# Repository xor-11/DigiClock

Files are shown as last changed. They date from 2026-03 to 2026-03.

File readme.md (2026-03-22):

<p align="center">
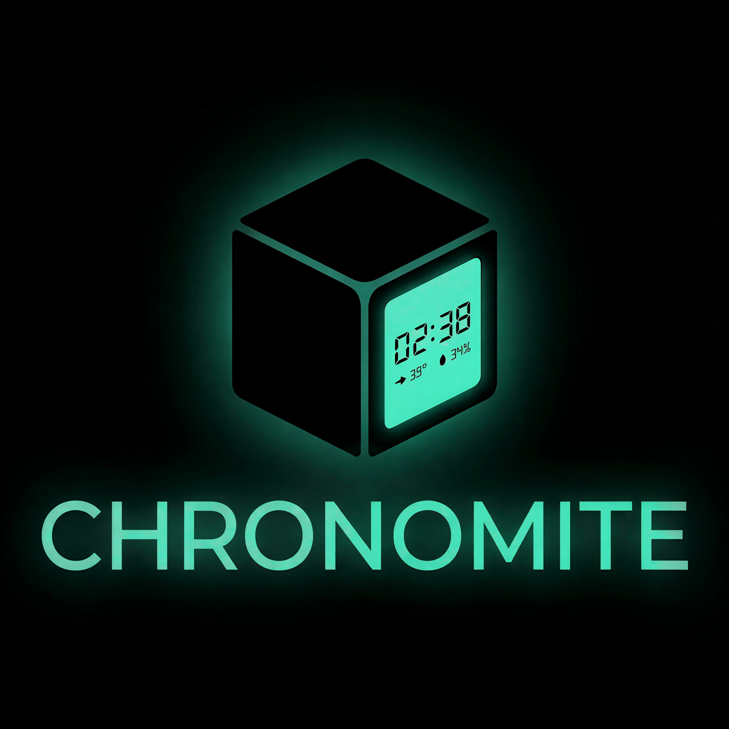
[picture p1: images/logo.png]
DigiClock Logo
  
</p>

<h1 align="center">DigiClock — ATtiny85 OLED Desk Clock</h1>

<p align="center">
  
  
  
  
  
  
</p>

<p align="center">
  A minimal, battery-powered real-time clock with temperature & humidity display,<br>
  built entirely on a Digispark ATtiny85 board with only 8KB of flash memory.<br>
  Housed in a custom 3D-printed enclosure.
</p>

---

## 📸 The Build

<p align="center">
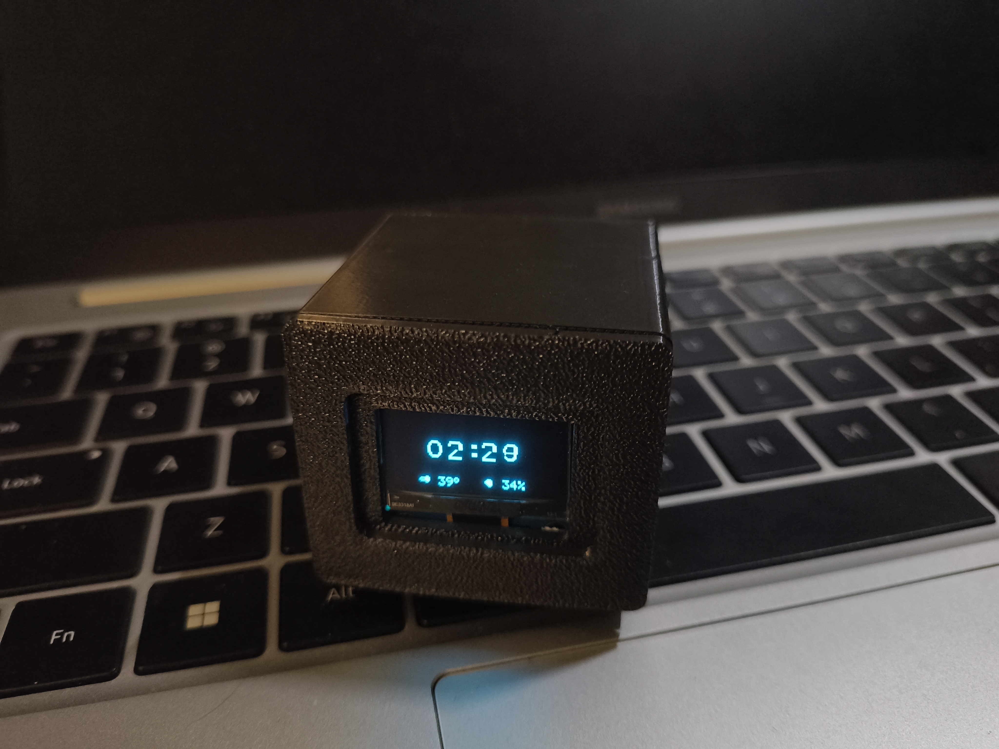
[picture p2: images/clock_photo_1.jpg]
Clock View 1
  
  &nbsp;&nbsp;
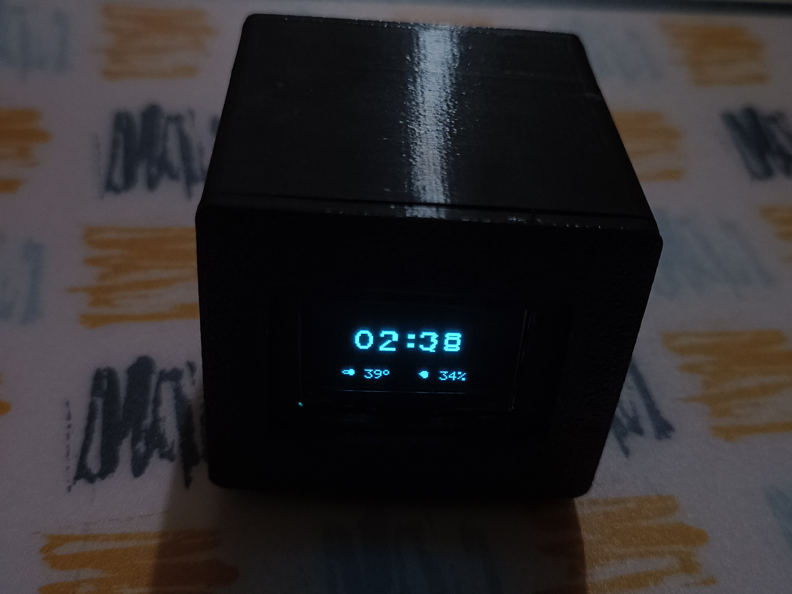
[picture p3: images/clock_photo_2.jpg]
Clock View 2
  
</p>

---

## ✨ Features

- **Real-Time Clock** — Hours, minutes & seconds via DS3231 RTC (I²C)
- **Blinking Colon** — Synced to even/odd seconds for accurate 1Hz blink
- **Temperature Display** — DHT11 reading with 70% scaling calibration
- **Humidity Display** — Relative humidity percentage
- **Smart Refresh** — Only redraws changed digits to eliminate flicker
- **Custom Pixel Fonts** — Hand-crafted 12×16 large digits, 5×8 small font, stored in PROGMEM
- **One-Button Time Set** — Single button adds 10 minutes per press with hold-repeat
- **Battery Powered** — 400mAh Li-Ion cell with TP4056 USB-C charging
- **3D-Printed Enclosure** — Print-ready STL files included
- **Tiny Footprint** — Entire firmware fits in ~6KB flash

---

## 🔌 Pin Diagram

<p align="center">
  Pin Diagram - Wiring Overview
</p>

---

## 🧩 Parts List

<table>
  <tr>
    <th align="center">#</th>
    <th align="left">Component</th>
    <th align="left">Specification</th>
    <th align="center">Qty</th>
  </tr>
  <tr>
    <td align="center">1</td>
    <td>Digispark Board</td>
    <td>ATtiny85 — Micro USB</td>
    <td align="center">1</td>
  </tr>
  <tr>
    <td align="center">2</td>
    <td>OLED Display</td>
    <td>SSD1306 128×64 I²C — 0.96"</td>
    <td align="center">1</td>
  </tr>
  <tr>
    <td align="center">3</td>
    <td>RTC Module</td>
    <td>DS3231 I²C — CR2032 backup</td>
    <td align="center">1</td>
  </tr>
  <tr>
    <td align="center">4</td>
    <td>Temp & Humidity Sensor</td>
    <td>DHT11</td>
    <td align="center">1</td>
  </tr>
  <tr>
    <td align="center">5</td>
    <td>Li-Ion Battery</td>
    <td>3.7V 400mAh</td>
    <td align="center">1</td>
  </tr>
  <tr>
    <td align="center">6</td>
    <td>Charging Module</td>
    <td>TP4056 — USB-C / Micro USB</td>
    <td align="center">1</td>
  </tr>
  <tr>
    <td align="center">7</td>
    <td>Tactile Push Button</td>
    <td>6×6mm momentary</td>
    <td align="center">1</td>
  </tr>
  <tr>
    <td align="center">8</td>
    <td>Connecting Wires</td>
    <td>Dupont / 28AWG silicone</td>
    <td align="center">—</td>
  </tr>
  <tr>
    <td align="center">9</td>
    <td>Enclosure</td>
    <td>3D Printed — STL files included</td>
    <td align="center">1</td>
  </tr>
</table>

---

## 🔗 Connections Summary

<table>
  <tr>
    <th align="center">ATtiny85 Pin</th>
    <th align="left">Connects To</th>
    <th align="center">Protocol</th>
  </tr>
  <tr>
    <td align="center">P0 (SDA)</td>
    <td>OLED SDA &nbsp;•&nbsp; DS3231 SDA</td>
    <td align="center">I²C</td>
  </tr>
  <tr>
    <td align="center">P2 (SCL)</td>
    <td>OLED SCL &nbsp;•&nbsp; DS3231 SCL</td>
    <td align="center">I²C</td>
  </tr>
  <tr>
    <td align="center">P3</td>
    <td>Push Button → GND</td>
    <td align="center">Digital Input</td>
  </tr>
  <tr>
    <td align="center">P4</td>
    <td>DHT11 Data Pin</td>
    <td align="center">One-Wire</td>
  </tr>
  <tr>
    <td align="center">5V</td>
    <td>TP4056 OUT+ → VCC Rail</td>
    <td align="center">Power</td>
  </tr>
  <tr>
    <td align="center">GND</td>
    <td>Common Ground</td>
    <td align="center">Power</td>
  </tr>
</table>

<br>

> **Power Chain:** Li-Ion Battery → TP4056 → Digispark 5V pin (regulated onboard)

---

## ⚡ How It Works

<pre>
┌─────────────┐    I²C     ┌──────────┐
│   DS3231    │◄──────────►│          │
│    RTC      │            │ ATtiny85 │──── P4 ──── DHT11
└─────────────┘            │ Digispark│
                           │          │──── P3 ──── Button
┌─────────────┐    I²C     │          │
│  SSD1306    │◄──────────►│          │
│  128×64     │            └──────────┘
└─────────────┘                 │
                           ┌────┴────┐
                           │ TP4056  │
                           │ Charger │
                           └────┬────┘
                           ┌────┴────┐
                           │ 400mAh  │
                           │ Li-Ion  │
                           └─────────┘
</pre>

### Clock Update Cycle
1. **Every 1 second** → Read DS3231 via I²C → update digits & colon
2. **Every 3 seconds** → Read DHT11 (interrupts disabled during read) → update temp/humidity
3. **On button press** → Add 10 minutes → write back to DS3231

### Smart Refresh System
Instead of redrawing the entire screen every second, the firmware tracks the last displayed value of every element. Only pixels that actually changed get rewritten — this eliminates flicker and reduces I²C bus load.

---

## 🖨️ 3D-Printed Enclosure

Print-ready files are available in the [`3d_files/`](3d_files/) folder.

### Print Settings (Recommended)

<table>
  <tr>
    <th align="left">Parameter</th>
    <th align="left">Value</th>
  </tr>
  <tr>
    <td>Layer Height</td>
    <td>0.2mm</td>
  </tr>
  <tr>
    <td>Infill</td>
    <td>20%</td>
  </tr>
  <tr>
    <td>Material</td>
    <td>PLA / PETG</td>
  </tr>
  <tr>
    <td>Supports</td>
    <td>As needed per model</td>
  </tr>
  <tr>
    <td>Wall Thickness</td>
    <td>1.2mm (3 walls)</td>
  </tr>
</table>

<br>

> **Tip:** Print a test fit first before final assembly. Tolerances may vary between printers.

---

## 🛠️ Build & Upload

### Prerequisites

<table>
  <tr>
    <th align="left">Software</th>
    <th align="left">Link</th>
  </tr>
  <tr>
    <td>Arduino IDE</td>
    <td><a href="https://www.arduino.cc/en/software">arduino.cc/en/software</a></td>
  </tr>
  <tr>
    <td>Digistump Board Package</td>
    <td><a href="https://github.com/digistump/DigistumpArduino">github.com/digistump/DigistumpArduino</a></td>
  </tr>
</table>

### Step 1 — Install Digispark Board Support

1. Open Arduino IDE → **File** → **Preferences**
2. In **Additional Board Manager URLs**, add:

<pre>
http://digistump.com/package_digistump_index.json
</pre>

3. Go to **Tools** → **Board** → **Board Manager**
4. Search `Digistump AVR` → Install
5. Select **Tools** → **Board** → **Digispark (Default - 16.5mhz)**

### Step 2 — Install Required Library

1. Go to **Sketch** → **Include Library** → **Manage Libraries**
2. Search & install: `TinyWireM`

> **Note:** No other libraries needed — the OLED driver, fonts, and DHT reader are all built into the sketch.

### Step 3 — Upload

1. Open `DigiClock.ino` in Arduino IDE
2. Click **Upload**
3. When the IDE says **"Plug in device now..."**, connect your Digispark via USB
4. Upload completes automatically via the Micronucleus bootloader

> ⚠️ **Do NOT plug in the Digispark before clicking Upload.** The bootloader only listens for 5 seconds on power-up.

---

## 📐 Display Layout

<pre>
     Column:  0       30                              110  127
              ┌────────────────────────────────────────────┐
    Page 0    │                                            │
    Page 1    │        ██  ██       ██  ██                 │
    Page 2    │        ██  ██  ••   ██  ██    seconds      │
    Page 3    │                                            │
    Page 4    │                        :SS                 │
    Page 5    │                                            │
    Page 6    │                                            │
    Page 7    │  🌡  24°C          💧  55%                │
              └────────────────────────────────────────────┘
</pre>

---

## 🔧 Calibration Notes

- **Temperature Scaling:** The displayed temperature is `raw × 0.70` (70%). This was calibrated against a reference thermometer for this specific DHT11 unit. Adjust the line `display_temp = (temp * 70) / 100;` in the code to match your sensor.
- **Button Behavior:** Each press adds +10 minutes. Hold for auto-increment. There's no separate hour/minute mode to keep the code minimal.

---

## 📁 Repository Structure

<pre>
DigiClock/
├── README.md               ← You are here
├── LICENSE                 ← MIT License
├── DigiClock.ino           ← Main firmware (single file)
├── images/
│   ├── logo.png            ← Project logo
│   ├── pin_diagram.png     ← Wiring diagram
│   ├── clock_photo_1.jpg   ← Build photo
│   └── clock_photo_2.jpg   ← Build photo
└── 3d_files/
    └── enclosure       ← 3D printable case
</pre>

---

## 📝 Known Limitations

- DHT11 accuracy is ±2°C / ±5% RH — it's not a precision instrument
- The 70% temperature scaling is specific to my unit; yours may differ
- Digispark USB pins (P3/P4) are shared with the sensor and button — **unplug USB before normal operation** to avoid interference
- No AM/PM indicator — runs in 24-hour format only
- DS3231 backup battery (CR2032) keeps time when main power is off

---

## 📜 License

This project is licensed under the **MIT License** — see the [LICENSE](LICENSE) file for details.

---

<p align="center">
  Built with ☕ and an 8-bit chip that has less RAM than this README.
</p>

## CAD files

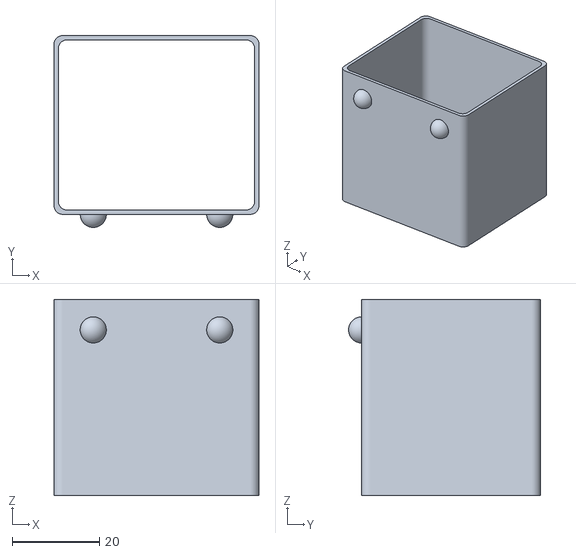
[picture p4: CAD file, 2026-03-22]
3d_files/main_clock.stl
47.0 x 44.0 x 45.0

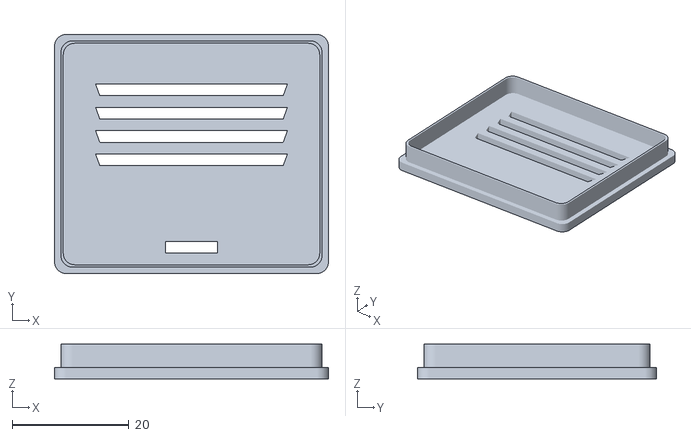
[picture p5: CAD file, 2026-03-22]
3d_files/back_clock.stl
47.0 x 41.0 x 6.00

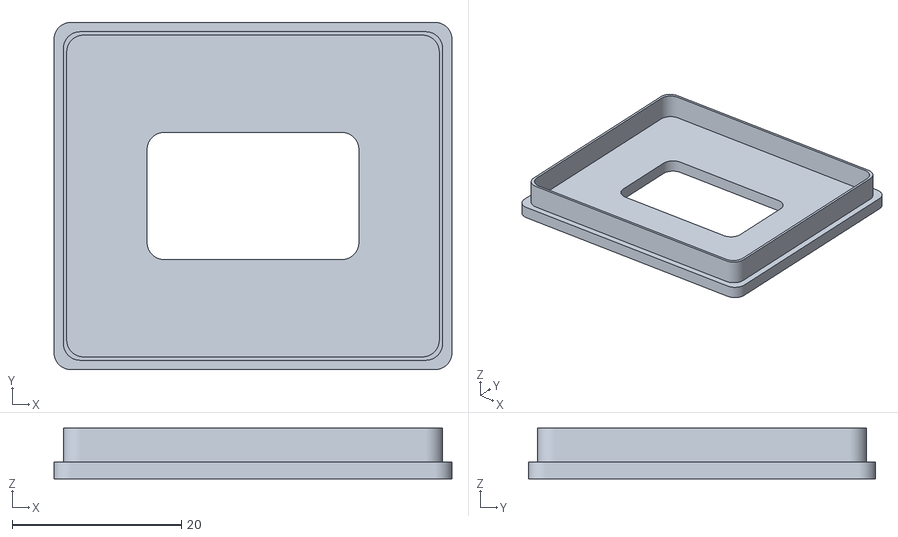
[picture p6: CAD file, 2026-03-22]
3d_files/front_clock.stl
47.0 x 41.0 x 6.00

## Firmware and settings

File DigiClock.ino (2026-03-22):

#include <TinyWireM.h>

#define DHT_PIN 4
#define BTN_PIN 3
#define RTC_ADDR 0x68
#define OLED_ADDR 0x3C

const unsigned long DHT_INTERVAL = 3000;
const unsigned long CLK_INTERVAL = 1000;

uint8_t h, m, s;
int8_t temp = 0, hum = 0;
int8_t display_temp = 0;
bool colonState = true;

uint8_t last_h = 255, last_m = 255, last_s = 255;
int8_t last_display_temp = -127, last_hum = -1;
bool last_colon = false;

unsigned long prevTime_DHT = 0;
unsigned long prevTime_CLK = 0;

const uint8_t digitsTop[] PROGMEM = {
  0xFC,0xFE,0x06,0x02,0x02,0x02,0x02,0x02,0x06,0xFE,0xFC,0x00,
  0x00,0x08,0x04,0xFE,0xFE,0x00,0x00,0x00,0x00,0x00,0x00,0x00,
  0x04,0x06,0x02,0x02,0x82,0xC2,0x62,0x36,0x1E,0x0C,0x00,0x00,
  0x04,0x06,0x02,0x22,0x22,0x22,0x36,0x7E,0xDC,0x80,0x00,0x00,
  0x80,0xC0,0x60,0x30,0x18,0x0C,0xFE,0xFE,0x00,0x00,0x00,0x00,
  0x3E,0x3E,0x22,0x22,0x22,0x22,0x62,0xC2,0x82,0x00,0x00,0x00,
  0xF8,0xFC,0x26,0x22,0x22,0x22,0x26,0xE4,0xC0,0x00,0x00,0x00,
  0x02,0x02,0x02,0x82,0xC2,0x62,0x32,0x1A,0x0E,0x06,0x00,0x00,
  0x1C,0xBE,0xE2,0xC2,0xC2,0xC2,0xE2,0xBE,0x1C,0x00,0x00,0x00,
  0x3C,0x7E,0xC2,0x82,0x82,0x82,0xC6,0xFE,0xFC,0x00,0x00,0x00,
};

const uint8_t digitsBot[] PROGMEM = {
  0x3F,0x7F,0x60,0x40,0x40,0x40,0x40,0x40,0x60,0x7F,0x3F,0x00,
  0x00,0x40,0x40,0x7F,0x7F,0x40,0x40,0x00,0x00,0x00,0x00,0x00,
  0x60,0x70,0x58,0x4C,0x46,0x43,0x41,0x40,0x40,0x40,0x00,0x00,
  0x01,0x41,0x40,0x44,0x44,0x44,0x6C,0x7E,0x3B,0x01,0x00,0x00,
  0x01,0x01,0x01,0x01,0x01,0x01,0x7F,0x7F,0x01,0x01,0x00,0x00,
  0x01,0x41,0x40,0x40,0x40,0x40,0x60,0x3F,0x1F,0x00,0x00,0x00,
  0x1F,0x3F,0x60,0x44,0x44,0x44,0x64,0x3C,0x18,0x00,0x00,0x00,
  0x00,0x00,0x00,0x7F,0x7F,0x00,0x00,0x00,0x00,0x00,0x00,0x00,
  0x39,0x7D,0x47,0x43,0x43,0x43,0x47,0x7D,0x39,0x00,0x00,0x00,
  0x00,0x00,0x03,0x47,0x44,0x44,0x64,0x3F,0x1F,0x00,0x00,0x00,
};

const uint8_t font5x8[] PROGMEM = {
  0x3E,0x51,0x49,0x45,0x3E,
  0x00,0x42,0x7F,0x40,0x00,
  0x62,0x51,0x49,0x49,0x46,
  0x22,0x41,0x49,0x49,0x36,
  0x18,0x14,0x12,0x7F,0x10,
  0x27,0x45,0x45,0x45,0x39,
  0x3C,0x4A,0x49,0x49,0x30,
  0x01,0x71,0x09,0x05,0x03,
  0x36,0x49,0x49,0x49,0x36,
  0x06,0x49,0x49,0x29,0x1E,
  0x00,0x00,0x00,0x00,0x00,
  0x06,0x09,0x09,0x06,0x00,
  0x3E,0x41,0x41,0x41,0x22,
  0x23,0x13,0x08,0x64,0x62,
};

const uint8_t secFont[] PROGMEM = {
  0x3E,0x51,0x49,0x45,0x3E,
  0x00,0x42,0x7F,0x40,0x00,
  0x62,0x51,0x49,0x49,0x46,
  0x22,0x41,0x49,0x49,0x36,
  0x18,0x14,0x12,0x7F,0x10,
  0x27,0x45,0x45,0x45,0x39,
  0x3C,0x4A,0x49,0x49,0x30,
  0x01,0x71,0x09,0x05,0x03,
  0x36,0x49,0x49,0x49,0x36,
  0x06,0x49,0x49,0x29,0x1E,
};

const uint8_t colonTop[] PROGMEM = {0x00,0x00,0x18,0x18,0x00,0x00,0x00,0x00};
const uint8_t colonBot[] PROGMEM = {0x00,0x00,0x18,0x18,0x00,0x00,0x00,0x00};

const uint8_t iconTemp[] PROGMEM = {0x18,0x24,0x24,0x24,0x24,0x24,0x18,0x00};
const uint8_t iconHum[]  PROGMEM = {0x00,0x0C,0x12,0x12,0x12,0x0C,0x00,0x00};

void oledCmd(uint8_t c) {
  TinyWireM.beginTransmission(OLED_ADDR);
  TinyWireM.send(0x00);
  TinyWireM.send(c);
  TinyWireM.endTransmission();
}

void oledData(uint8_t d) {
  TinyWireM.beginTransmission(OLED_ADDR);
  TinyWireM.send(0x40);
  TinyWireM.send(d);
  TinyWireM.endTransmission();
}

void oledPos(uint8_t x, uint8_t page) {
  oledCmd(0xB0 + (page & 0x07));
  oledCmd(0x00 + (x & 0x0F));
  oledCmd(0x10 + (x >> 4));
}

void oledInit() {
  oledCmd(0xAE);
  oledCmd(0x20); oledCmd(0x00);
  oledCmd(0x40);
  oledCmd(0xA0);
  oledCmd(0xC0);
  oledCmd(0x81); oledCmd(0xCF);
  oledCmd(0xA6);
  oledCmd(0xA8); oledCmd(0x3F);
  oledCmd(0xD3); oledCmd(0x00);
  oledCmd(0xD5); oledCmd(0x80);
  oledCmd(0xD9); oledCmd(0xF1);
  oledCmd(0xDA); oledCmd(0x12);
  oledCmd(0xDB); oledCmd(0x40);
  oledCmd(0x8D); oledCmd(0x14);
  oledCmd(0xAF);

  for (uint8_t p = 0; p < 8; p++) {
    oledPos(0, p);
    for (uint8_t i = 0; i < 128; i++) oledData(0x00);
  }
}

#define DIGIT_WIDTH 12
#define DIGIT_SPACING 2
#define COLON_WIDTH 8

void drawDigit(uint8_t d, uint8_t x, uint8_t p) {
  if (d > 9) return;

  oledPos(x, p);
  TinyWireM.beginTransmission(OLED_ADDR);
  TinyWireM.send(0x40);
  for (uint8_t i = 0; i < DIGIT_WIDTH; i++) {
    TinyWireM.send(pgm_read_byte(&digitsTop[d * DIGIT_WIDTH + i]));
  }
  TinyWireM.endTransmission();

  oledPos(x, p + 1);
  TinyWireM.beginTransmission(OLED_ADDR);
  TinyWireM.send(0x40);
  for (uint8_t i = 0; i < DIGIT_WIDTH; i++) {
    TinyWireM.send(pgm_read_byte(&digitsBot[d * DIGIT_WIDTH + i]));
  }
  TinyWireM.endTransmission();
}

void drawColon(uint8_t x, uint8_t p, bool on) {
  oledPos(x, p);
  TinyWireM.beginTransmission(OLED_ADDR);
  TinyWireM.send(0x40);
  for (uint8_t i = 0; i < 8; i++) {
    TinyWireM.send(on ? pgm_read_byte(&colonTop[i]) : 0x00);
  }
  TinyWireM.endTransmission();

  oledPos(x, p + 1);
  TinyWireM.beginTransmission(OLED_ADDR);
  TinyWireM.send(0x40);
  for (uint8_t i = 0; i < 8; i++) {
    TinyWireM.send(on ? pgm_read_byte(&colonBot[i]) : 0x00);
  }
  TinyWireM.endTransmission();
}

void drawSeconds(uint8_t x, uint8_t p) {
  oledPos(x, p);
  TinyWireM.beginTransmission(OLED_ADDR);
  TinyWireM.send(0x40);
  for (uint8_t i = 0; i < 16; i++) oledData(0x00);
  TinyWireM.endTransmission();

  oledPos(x, p);
  TinyWireM.beginTransmission(OLED_ADDR);
  TinyWireM.send(0x40);
  for (uint8_t i = 0; i < 5; i++) {
    TinyWireM.send(pgm_read_byte(&secFont[(s / 10) * 5 + i]));
  }
  TinyWireM.send(0x00);
  for (uint8_t i = 0; i < 5; i++) {
    TinyWireM.send(pgm_read_byte(&secFont[(s % 10) * 5 + i]));
  }
  TinyWireM.endTransmission();
}

void drawSmallChar(uint8_t idx) {
  TinyWireM.beginTransmission(OLED_ADDR);
  TinyWireM.send(0x40);
  for (uint8_t i = 0; i < 5; i++) {
    TinyWireM.send(pgm_read_byte(&font5x8[idx * 5 + i]));
  }
  TinyWireM.send(0x00);
  TinyWireM.endTransmission();
}

void drawSmallNum(int8_t n) {
  if (n < 0) {
    TinyWireM.beginTransmission(OLED_ADDR);
    TinyWireM.send(0x40);
    TinyWireM.send(0x08);
    TinyWireM.send(0x08);
    TinyWireM.send(0x08);
    TinyWireM.send(0x00);
    TinyWireM.endTransmission();
    n = -n;
  }
  if (n > 99) n = 99;
  drawSmallChar(n / 10);
  drawSmallChar(n % 10);
}

void drawIcon(const uint8_t* icon) {
  TinyWireM.beginTransmission(OLED_ADDR);
  TinyWireM.send(0x40);
  for (uint8_t i = 0; i < 8; i++) {
    TinyWireM.send(pgm_read_byte(&icon[i]));
  }
  TinyWireM.send(0x00);
  TinyWireM.endTransmission();
}

void updateDisplay() {
  const uint8_t TIME_X = 30;
  const uint8_t TIME_Y = 1;

  const uint8_t H1_X = TIME_X;
  const uint8_t H2_X = H1_X + DIGIT_WIDTH + DIGIT_SPACING;
  const uint8_t COLON_X = H2_X + DIGIT_WIDTH + DIGIT_SPACING;
  const uint8_t M1_X = COLON_X + COLON_WIDTH + DIGIT_SPACING;
  const uint8_t M2_X = M1_X + DIGIT_WIDTH + DIGIT_SPACING;

  const uint8_t SEC_X = TIME_X + 28;
  const uint8_t SEC_Y = 4;

  if (h != last_h) {
    drawDigit(h / 10, H1_X, TIME_Y);
    drawDigit(h % 10, H2_X, TIME_Y);
    last_h = h;
  }

  if (m != last_m) {
    drawDigit(m / 10, M1_X, TIME_Y);
    drawDigit(m % 10, M2_X, TIME_Y);
    last_m = m;
  }

  bool targetColon = (s % 2 == 0);
  if (targetColon != last_colon) {
    drawColon(COLON_X, TIME_Y, targetColon);
    last_colon = targetColon;
  }

  if (s != last_s) {
    drawSeconds(SEC_X, SEC_Y);
    last_s = s;
  }

  if (display_temp != last_display_temp || hum != last_hum) {
    oledPos(0, 7);
    for (uint8_t i = 0; i < 128; i++) oledData(0x00);

    oledPos(10, 7);
    drawIcon(iconTemp);
    drawSmallChar(10);
    drawSmallNum(display_temp);
    drawSmallChar(11);
    drawSmallChar(12);

    oledPos(70, 7);
    drawIcon(iconHum);
    drawSmallChar(10);
    drawSmallNum((uint8_t)hum);
    drawSmallChar(13);

    last_display_temp = display_temp;
    last_hum = hum;
  }
}

uint8_t b2d(uint8_t v) { return ((v >> 4) * 10) + (v & 0x0F); }
uint8_t d2b(uint8_t v) { return ((v / 10) << 4) | (v % 10); }

void readRTC() {
  TinyWireM.beginTransmission(RTC_ADDR);
  TinyWireM.send(0x00);
  TinyWireM.endTransmission();
  TinyWireM.requestFrom(RTC_ADDR, 3);
  if (TinyWireM.available() >= 3) {
    s = b2d(TinyWireM.receive() & 0x7F);
    m = b2d(TinyWireM.receive());
    h = b2d(TinyWireM.receive() & 0x3F);
  }
}

void setTime(uint8_t hr, uint8_t mn, uint8_t sc) {
  TinyWireM.beginTransmission(RTC_ADDR);
  TinyWireM.send(0x00);
  TinyWireM.send(d2b(sc));
  TinyWireM.send(d2b(mn));
  TinyWireM.send(d2b(hr));
  TinyWireM.endTransmission();
}

void readDHT() {
  uint8_t bits[5] = {0};
  uint8_t cnt = 7;
  uint8_t idx = 0;

  pinMode(DHT_PIN, OUTPUT);
  digitalWrite(DHT_PIN, LOW);
  delay(18);
  digitalWrite(DHT_PIN, HIGH);
  delayMicroseconds(40);
  pinMode(DHT_PIN, INPUT_PULLUP);

  noInterrupts();

  uint16_t loopCnt = 10000;
  while (digitalRead(DHT_PIN) == LOW) if (--loopCnt == 0) { interrupts(); return; }

  loopCnt = 10000;
  while (digitalRead(DHT_PIN) == HIGH) if (--loopCnt == 0) { interrupts(); return; }

  for (int i = 0; i < 40; i++) {
    loopCnt = 10000;
    while (digitalRead(DHT_PIN) == LOW) if (--loopCnt == 0) { interrupts(); return; }

    unsigned long t = micros();
    loopCnt = 10000;
    while (digitalRead(DHT_PIN) == HIGH) if (--loopCnt == 0) { interrupts(); return; }

    if ((micros() - t) > 40) bits[idx] |= (1 << cnt);
    if (cnt == 0) { cnt = 7; idx++; } else cnt--;
  }

  interrupts();

  uint8_t sum = bits[0] + bits[1] + bits[2] + bits[3];
  if (bits[4] == sum && sum != 0) {
    hum = bits[0];
    temp = bits[2];
    display_temp = (temp * 70) / 100;
  }
}

void setup() {
  delay(500);
  TinyWireM.begin();
  oledInit();
  pinMode(BTN_PIN, INPUT_PULLUP);

  readRTC();
  readDHT();

  last_h = last_m = last_s = 255;
  last_display_temp = -127;
  last_hum = -1;
  last_colon = !(s % 2 == 0);
  updateDisplay();
}

void loop() {
  unsigned long now = millis();

  if (digitalRead(BTN_PIN) == LOW) {
    delay(50);
    if (digitalRead(BTN_PIN) == LOW) {
      m += 10;
      if (m >= 60) {
        m -= 60;
        h++;
        if (h > 23) h = 0;
      }
      s = 0;
      setTime(h, m, s);
      last_h = last_m = last_s = 255;
      updateDisplay();

      unsigned long waitStart = millis();
      while (digitalRead(BTN_PIN) == LOW) {
        if (millis() - waitStart > 2000) break;
      }
      delay(100);
    }
  }

  if (now - prevTime_CLK >= CLK_INTERVAL) {
    prevTime_CLK = now;
    readRTC();
    updateDisplay();
  }

  if (now - prevTime_DHT >= DHT_INTERVAL) {
    prevTime_DHT = now;
    readDHT();
  }
}
